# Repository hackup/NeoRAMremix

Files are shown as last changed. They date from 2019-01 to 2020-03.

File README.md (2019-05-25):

# NeoRAM Remix

The NeoRAM is a RAM extension for the Commodore 64/128 computers that is compatible with the GeoRAM modules. It features up to 2MB of RAM and it is battery buffered. A single CR2032 cell will usually preserve the data stored in the NeoRAM for several months.

The "remix" version is based on the [original NeoRAM](http://www.x1541.de/) developed by Nicolas Welte in 2006. Without further consent, both the original and the remix version are licensed for personal and non-commercial use only (see details below). There is also no warranty whatsoever. **USE AT YOUR OWN RISK!**.

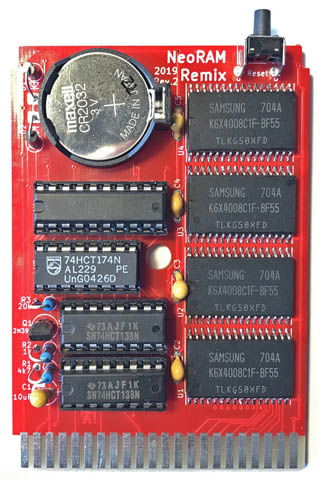
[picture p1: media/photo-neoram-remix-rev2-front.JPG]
NeoRAM Remix Rev.2 Front

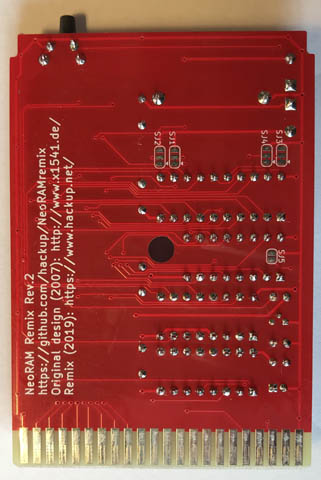
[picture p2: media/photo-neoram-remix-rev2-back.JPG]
NeoRAM Remix Rev.2 Back


## Configurations

The NeoRAM can be assembled in different configurations. By default, the PCB is configured for 2MB of RAM and battery buffering. There is no need to change any of the solder jumpers if the board is assembled completely.

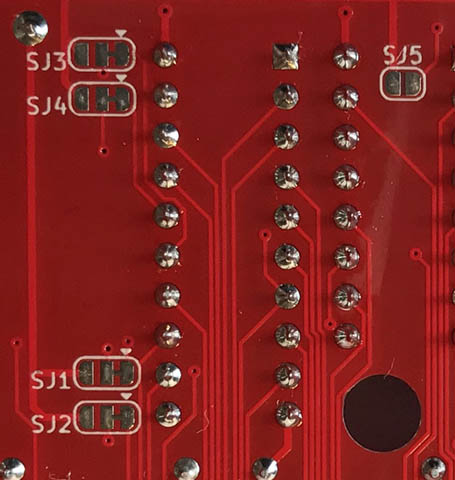
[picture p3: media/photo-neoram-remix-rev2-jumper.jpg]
Configuration Jumpers


If you choose to fit fewer RAM chips their respective decoupling caps can be omitted as well. The solder jumpers SJ3 and SJ4 on the backside of the PCB have to be changed to reflect the memory configuration:

| RAM | SJ3 | SJ4 | ICs | Caps  |
|---|-----|-----|---|---|
| 2MB | 1-2 | 1-2 | U1-U4 | C2-C5 |
| 1MB | 1-2 | 2-3 | U1-U2 | C2-C3 |
| 512kB  | 2-3 | 2-3 | U1 | C2 |

If you decide you don't need the battery buffering, the following components can be omitted: BT1, D1, C1, R1-3, Q1. If you skip these components you need to close the solder jumper SJ5 on the back of the PCB. Also note that D2 is still required.

See the [NeoRAM Remix blog post](https://www.hackup.net/2019/04/the-neoram-remix/) for more details and the bill of materials.

## License


This work is licensed under a
[Creative Commons Attribution-NonCommercial-ShareAlike 4.0 International License](http://creativecommons.org/licenses/by-nc-sa/4.0/).

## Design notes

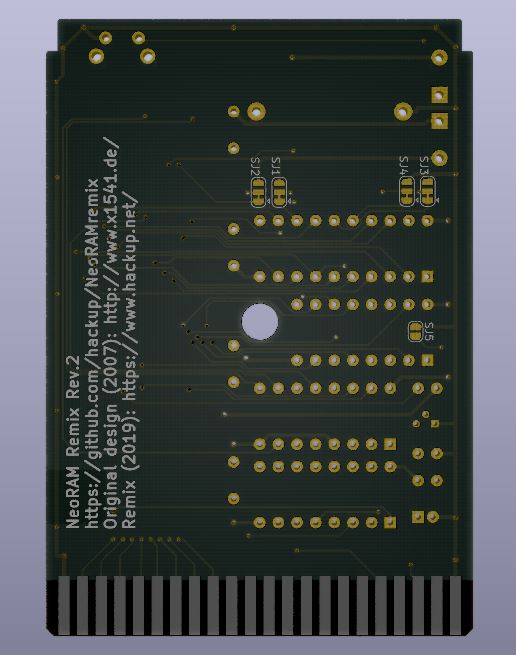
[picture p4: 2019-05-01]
media/neoram-remix-rev2-back.JPG

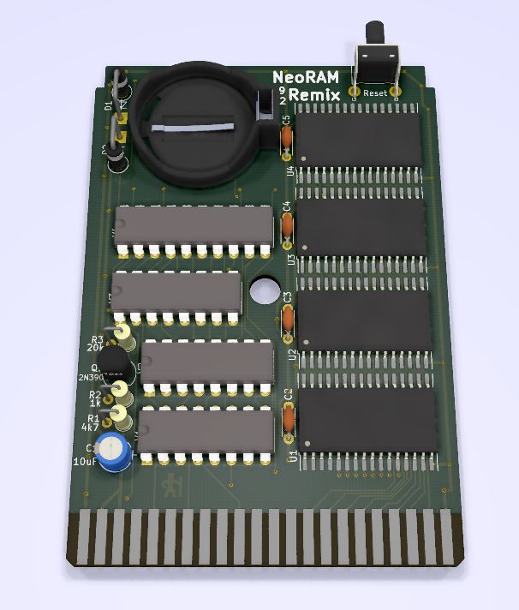
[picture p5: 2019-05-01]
media/neoram-remix-rev2-front.JPG

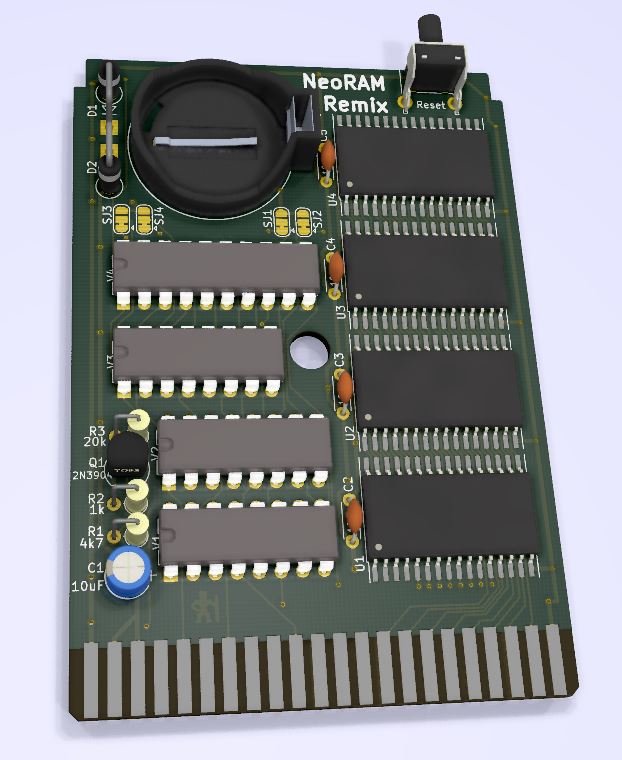
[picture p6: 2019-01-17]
media/neoram-remix-rev1.JPG

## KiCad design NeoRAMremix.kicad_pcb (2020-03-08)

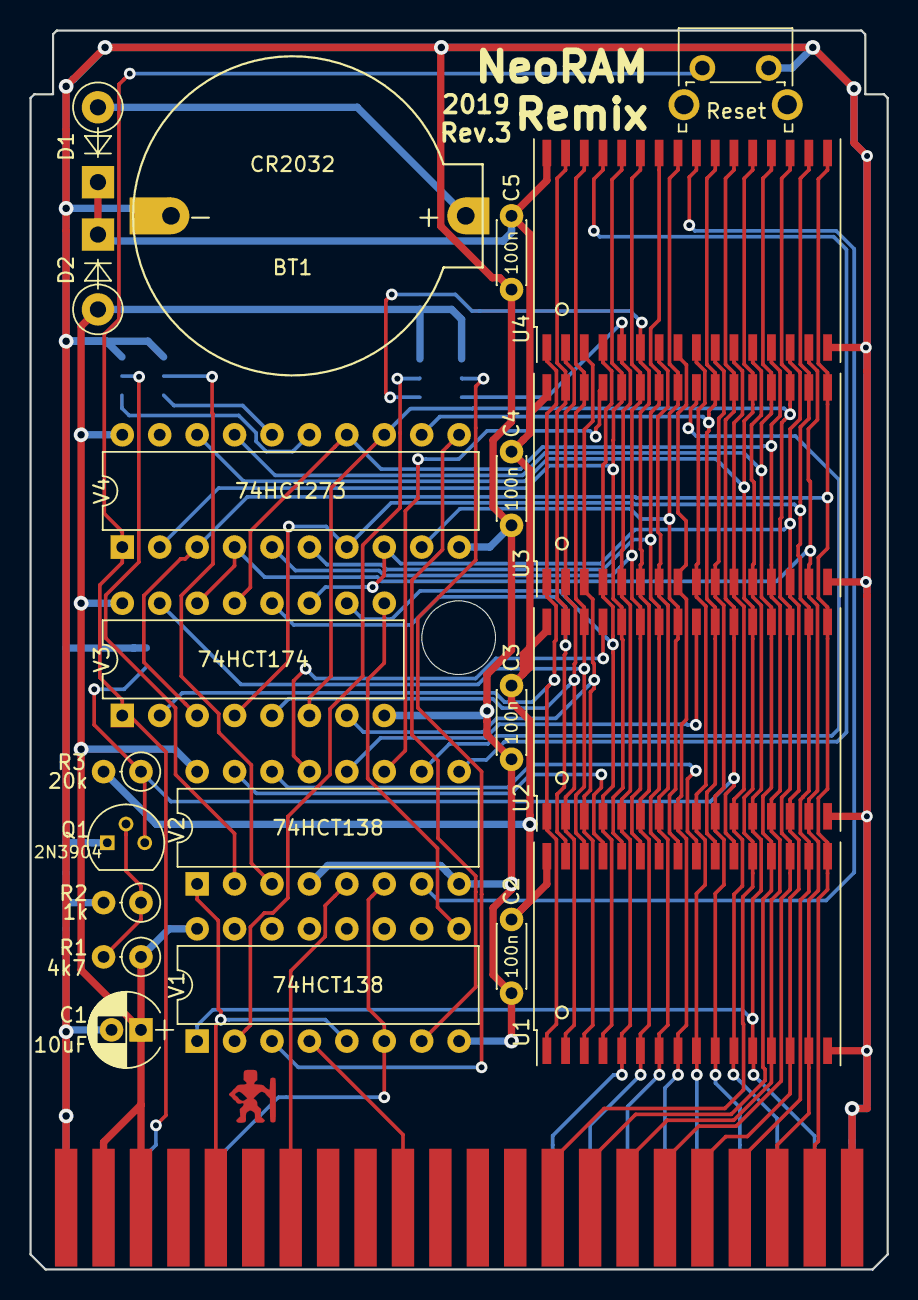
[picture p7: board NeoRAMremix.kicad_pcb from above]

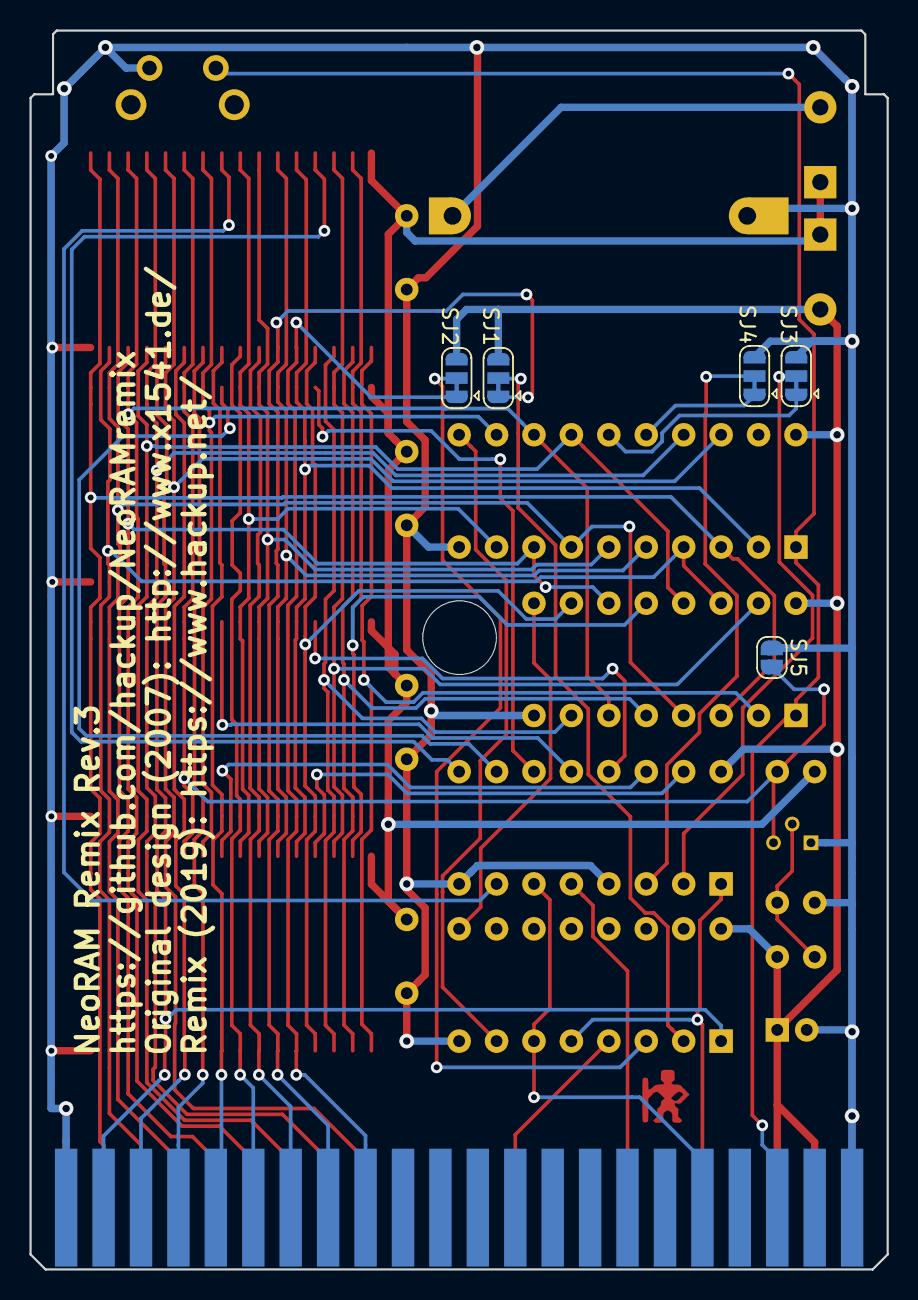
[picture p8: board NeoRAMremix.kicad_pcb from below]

Board: 2 copper layers, 58.2 x 84.1 mm, 28 parts (5 on the bottom side), 54 nets.

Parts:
BT1: CR2032; Battery-Holder-CR2032
C1: 10uF; CP_Radial_D5.0mm_P2.00mm
C2, C3, C4, C5: 100n; C_Disc_D4.3mm_W1.9mm_P5.00mm
D1, D2: 1N5817; D_DO-41_SOD81_P5.08mm_Vertical_KathodeUp
H1: MountingHole; MountingHole_5mm
P1: C64-Exp-Port; C64-Cart-NoSilkS
Q1: 2N3904; TO-92_Molded_Narrow
R1: 4k7; R_Axial_DIN0207_L6.3mm_D2.5mm_P2.54mm_Vertical
R2: 1k; R_Axial_DIN0207_L6.3mm_D2.5mm_P2.54mm_Vertical
R3: 20k; R_Axial_DIN0207_L6.3mm_D2.5mm_P2.54mm_Vertical
SJ1, SJ2, SJ3, SJ4: SolderJumper_3_Bridged12; SolderJumper-3_P1.3mm_Bridged12
SJ5: no_battery; SolderJumper-2_P1.3mm_Open_RoundedPad1.0x1.5mm
SW1: Reset; SW_Tactile_SPST_Angled_PTS645Vx83-2LFS
U1, U2, U3, U4: HM628512BFP-5; SO32_FP32D_20.45x11.3mm_Pitch1.27mm
V1, V2: 74HCT138; DIP-16_W7.62mm
V3: 74HCT174; DIP-16_W7.62mm
V4: 74HCT273; DIP-20_W7.62mm

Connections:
+5V: C1.1, D2.2, P1.2, P1.3, R1.1, SJ1.3, SJ2.3, V1.16, V2.16, V3.16, V4.20
+BATT: C2.1, C3.1, C4.1, C5.1, D1.1, D2.1, R3.2, U1.32, U2.32, U3.32, U4.32
/A0: P1.Y, U1.12, U2.12, U3.12, U4.12, V1.1
/A1: P1.X, U1.11, U2.11, U3.11, U4.11
/A2: P1.W, U1.10, U2.10, U3.10, U4.10
/A3: P1.V, U1.9, U2.9, U3.9, U4.9
/A4: P1.U, U1.8, U2.8, U3.8, U4.8
/A5: P1.T, U1.7, U2.7, U3.7, U4.7
/A6: P1.S, SJ1.1, U1.6, U2.6, U3.6, U4.6
/A7: P1.R, SJ2.1, U1.5, U2.5, U3.5, U4.5
/D0: P1.16, U1.13, U2.13, U3.13, U4.13, V3.13, V4.14
/D1: P1.18, U1.14, U2.14, U3.14, U4.14, V3.11, V4.8
/D2: P1.20, U1.15, U2.15, U3.15, U4.15, V3.14, V4.4
/D3: P1.21, U1.17, U2.17, U3.17, U4.17, V3.3, V4.3
/D4: P1.19, U1.18, U2.18, U3.18, U4.18, V3.4, V4.7
/D5: P1.17, U1.19, U2.19, U3.19, U4.19, V3.6, V4.13
/D6: P1.15, U1.20, U2.20, U3.20, U4.20, V4.17
/D7: P1.14, U1.21, U2.21, U3.21, U4.21, V4.18
/RA8: U1.27, U2.27, U3.27, U4.27, V4.5
/RA9: U1.26, U2.26, U3.26, U4.26, V4.6
/RA10: U1.23, U2.23, U3.23, U4.23, V4.12
/RA11: U1.25, U2.25, U3.25, U4.25, V4.9
/RA12: U1.4, U2.4, U3.4, U4.4, V3.10
/RA13: U1.28, U2.28, U3.28, U4.28, V4.2
/RA14: U1.3, U2.3, U3.3, U4.3, V3.7
/RA15: U1.31, U2.31, U3.31, U4.31, V3.12
/RA16: U1.2, U2.2, U3.2, U4.2, V3.5
/RA17: U1.30, U2.30, U3.30, U4.30, V3.15
/RA18: U1.1, U2.1, U3.1, U4.1, V3.2
GND: BT1.2, C1.2, C2.2, C3.2, C4.2, C5.2, P1.1, P1.22, P1.A, P1.Z, Q1.1, R2.2, SJ3.3, SJ4.3, SJ5.1, SW1.2, U1.16, U2.16, U3.16, U4.16, V1.8, V2.4, V2.8, V3.8, V4.10
unnamed: BT1.1, D1.2
unnamed: P1.5, V1.5, V2.1
unnamed: P1.7, V2.5
unnamed: P1.10, V1.4
unnamed: P1.C, SW1.1, V3.1, V4.1
unnamed: P1.E, V1.6, V2.6
unnamed: Q1.2, R1.2, R2.1
unnamed: Q1.3, R3.1, SJ5.2, U1.22, U2.22, U3.22, U4.22
unnamed: SJ1.2, V1.2
unnamed: SJ2.2, V1.3
unnamed: SJ3.1, V4.15
unnamed: SJ3.2, V2.2
unnamed: SJ4.1, V4.16
unnamed: SJ4.2, V2.3
unnamed: U1.24, V2.14
unnamed: U1.29, V2.15
unnamed: U2.24, V2.12
unnamed: U2.29, V2.13
unnamed: U3.24, V2.10
unnamed: U3.29, V2.11
unnamed: U4.24, V2.7
unnamed: U4.29, V2.9
unnamed: V1.7, V4.11
unnamed: V1.9, V3.9

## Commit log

2019-01-08 Initial import.
    [NeoRAMremix.kicad_pcb, NeoRAMremix.sch]
2019-01-09 Completed and fixed schematics.
    [NeoRAMremix.sch]
2019-01-10 Started layout.
    [NeoRAMremix.kicad_pcb, NeoRAMremix.sch]
2019-01-10 More layout.
    [NeoRAMremix.kicad_pcb]
2019-01-10 First complete layout.
    [NeoRAMremix.kicad_pcb]
2019-01-10 Reset switch.
    [NeoRAMremix.kicad_pcb, NeoRAMremix.sch]
2019-01-11 Fixed solder bridges.
    [NeoRAMremix.sch]
2019-01-11 Reduced board size and updated layout.
    [NeoRAMremix.kicad_pcb]
2019-01-14 Reduced board width.
    [NeoRAMremix.kicad_pcb]
2019-01-16 Fixing RAM footprint.
    [NeoRAMremix.sch]
2019-01-17 Preparing for rev.1
    [NeoRAMremix.kicad_pcb]
2019-04-19 Fixed footprint.
    [NeoRAMremix.kicad_pcb]
2019-04-28 Added license info.
    [NeoRAMremix.kicad_pcb, NeoRAMremix.sch]
2019-04-28 Added JP1 to disable battery circuit for /CS.
    [NeoRAMremix.kicad_pcb, NeoRAMremix.sch]
2019-04-28 Added repo URL.
    [NeoRAMremix.kicad_pcb]
2019-04-28 More room for JP1.
    [NeoRAMremix.kicad_pcb]
2019-04-28 Improved solder jumper footprint.
    [NeoRAMremix.kicad_pcb, NeoRAMremix.sch]
2019-05-01 Replaced JP1 with solder jumber SJ5.
    [NeoRAMremix.kicad_pcb, NeoRAMremix.sch]
2019-05-08 Updated battery holder again.
    [NeoRAMremix.kicad_pcb]
2019-05-25 Added Gerber files to repo.
2020-03-08 Fixed revision number on bottom side.
    [NeoRAMremix.kicad_pcb]
